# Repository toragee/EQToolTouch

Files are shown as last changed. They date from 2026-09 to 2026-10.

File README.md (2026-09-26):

# EQToolTouch

ESP32-C6 기반 차압(differential pressure) 측정기.
Waveshare **ESP32-C6-Touch-LCD-1.47** 보드에 **XGZP6899A** 아날로그 압력
센서를 붙여, LVGL 차트로 실시간 표시하고 WiFi AP + 웹소켓으로
PC / 안드로이드에 스트리밍한다.

## 저장소 구조

```
EQTool/          아두이노 스케치 (펌웨어)  <- 여기가 본체
  README.md      핀맵, 전원 관리, 문제 해결 기록. 먼저 읽을 것
case/            케이스 설계
  stl/           출력용 STL
  XGZP6899A.step 센서 3D 모델 (데이터시트 도면으로 생성)
  ESP32-C6-Touch-LCD-1.47-2D3D/   보드 2D/3D (Waveshare 배포본)
```

## 브랜치

센서 하드웨어 리비전에 따라 갈라진다.

| 브랜치 | 센서 | 상태 |
|---|---|---|
| `sensor-analog` | **XGZP6899A** 040KPDPN (아날로그, ±40 kPa) | 동작 확인됨. 고정 |
| `main` | 위와 동일 | 현행 개발 라인 |

**현재 두 브랜치의 펌웨어는 같다.** 센서 수급 문제로 교체한 부품
(`6899A040KPDPN`, 각인 `6899 040A`)이 기존과 **동일한 아날로그 부품**이라
코드 변경이 필요 없었다. 판매처가 I2C 라고 표기했더라도 각인을 믿을 것.

`XGZP6899` 바로 뒤 한 글자가 출력 방식이다. **`A` = 아날로그, `D` = I2C.**
`6899A040KPDPN` 은 아날로그, `6899D040KPDPN` 이 I2C 다.
수급 문제로 센서를 바꿀 때 이 글자를 반드시 확인할 것.

### 아날로그 버전(`sensor-analog`)의 특징

- 출력이 ADC 한 핀(**GPIO4**)뿐이라 **약 980 Hz** 로 샘플링한다
- 부팅 시 0.5초 평균으로 영점을 잡고, 그 전압이 VDD 의 몇 %인지로
  DPN(양방향) / DG(단방향)를 자동 판별한다

> **I2C 버전으로 가면 샘플레이트를 유지할 수 없다.** 한 샘플마다
> 변환 명령 → 대기 → 3바이트 읽기가 필요해서 현실적으로 100 Hz 이하가 된다.
> 터치(0x63)·IMU(0x6B)와 버스를 공유하는 부담도 있다.
> 빠른 압력 변화를 봐야 한다면 아날로그 쪽이 유리하다.

## 빠른 시작

1. 아두이노 IDE 2.x, 보드 패키지 **esp32 by Espressif**
2. Waveshare 위키에서 `ESP32-C6-Touch-LCD-1.47-Demo` 를 받아
   그 안의 `Arduino/libraries` 를 스케치북 라이브러리로 설치
   (lvgl 8.4.0 / GFX_Library_for_Arduino 1.5.9 / esp_lcd_touch_axs5106l / FastIMU)
3. `EQTool/EQTool.ino` 를 열고 Tools 설정을 맞춘 뒤 업로드

> **용량이 커서 벤더 데모(155MB)와 zip 파일은 저장소에 포함하지 않았다.**
> 버전이 맞지 않으면 빌드가 조용히 깨지므로, 요구 버전은
> `EQTool/README.md` 의 "빌드" 항목을 그대로 따를 것.

자세한 내용(핀맵, 조작, 전원 관리, 그동안 겪은 문제와 해결)은
**[EQTool/README.md](EQTool/README.md)** 에 정리되어 있다.

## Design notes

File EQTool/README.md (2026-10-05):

# EQTool

ESP32-C6 기반 압력 측정 도구. Waveshare **ESP32-C6-Touch-LCD-1.47** 보드에서
**XGZP6899A** 아날로그 압력 센서를 읽어 LVGL 차트로 실시간 표시하고,
WiFi AP + 내장 웹서버로 PC/안드로이드에 실시간 스트리밍한다.

## 하드웨어

| 항목 | 내용 |
|---|---|
| MCU 보드 | Waveshare **ESP32-C6-Touch-LCD-1.47** (JD9853 172x320 IPS + AXS5106L 터치) |
| 센서 | CFSensor XGZP6899A (40 kPa, 아날로그 전압 출력) |
| 화면 방향 | 가로 (320 x 172), `LCD_ROTATION 3` (Arduino_GFX 기준) |

### 보드 핀맵 (ESP32-C6-Touch-LCD-1.47)

| 기능 | 핀 |
|---|---|
| LCD (JD9853) | SCK=1, MOSI=2, CS=14, DC=15, RST=22, BL=23 |
| TF 카드 | SCK=1, MOSI=2, MISO=3, CS=4 (SPI 공유) |
| 터치 / IMU (I2C) | SDA=18, SCL=19, TP_RST=20, TP_INT=21 |
| 배터리 전압 | GPIO0 (ADC) |
| BOOT 버튼 | GPIO9 (Y축 전환. 화면 터치와 동일 동작) |
| IMU (QMI8658) INT | **GPIO5 = IMU_INT1, GPIO6 = IMU_INT2** |
| **압력 센서 OUT** | **GPIO4** (TF CS 자리) |

> ESP32-C6 의 ADC1 은 GPIO0~6 뿐인데 회로도상 전부 물려 있다.
> GPIO5/GPIO6 은 QMI8658 IMU 가 **능동으로 구동**하므로 아날로그 입력으로 못 쓴다.
> (붙여 보면 센서 출력이 IMU 에 끌려 내려가고 `adc oneshot read fail` 이 뜬다.)
> 남는 선택지는 **GPIO4** 뿐 — TF 카드를 포기하는 대신 쓴다. 10K 풀업이 하나
> 붙어 있지만 센서 출력단 임피던스가 낮아 오차는 무시할 수준이다.
> 데모 코드만 보고 GPIO5/6 이 비었다고 추정하면 안 된다. **회로도를 볼 것.**

### 배선

| 센서 핀 | 신호 | ESP32-C6 | 헤더 |
|---|---|---|---|
| 2 | GND | GND | H1 3 / 4 / 6번 |
| 5 | OUT | **GPIO3** (ADC1_CH3) | **H1 15번 (IO3)** |
| 6 | VDD | 3V3 | H1 8번 |
| 1, 3, 4, 7, 8 | N/C | 연결하지 않음 | |

GPIO4(TF CS)가 아니라 GPIO3(TF MISO)를 쓴다. GPIO4 는 ESP32-C6 의 JTAG
MTMS 겸용이라 리셋 직후 내부 풀업이 걸릴 수 있고, 그러면 "미연결"과
"센서가 레일을 구동 중"을 ADC 값만으로 구분하기 어렵다. GPIO3 은 그런
겸용 기능이 없다. TF 카드는 쓰지 않으므로 둘 다 비어 있다.

#### OUT 핀은 번호로 세지 말고 전압으로 찾을 것

데이터시트의 SOP8 핀 테이블은 **윗면 기준**이다. 센서를 바닥에서 보고
번호를 세면 좌우가 뒤집히고, 그 상태로 배선하면 아무 데이터도 안 들어온다.
센서에 전원(2번 GND / 6번 VDD)만 넣고 리드 8개를 하나씩 찍으면 바로 나온다.

| 측정값 | 정체 |
|---|---|
| 3.3 V | VDD |
| 0 V | GND |
| **1~2 V** | **OUT** |
| 뜨거나 불안정 | N/C |

OUT 자리가 레일(0 V 또는 VDD 근처)에 고착돼 있으면 **센서 불량**이다.
`XGZPA_Init()` 이 무압 출력을 VDD 의 5~90% 범위로 검사해 이 상태를 잡아낸다.

> **주의** — 이 시리즈는 각인으로 출력 타입을 확정할 수 없다.
> CFSensor 품번은 `XGZP6899`**`A`**`040KPDPN` 처럼 출력 타입 글자가 측정 범위
> **앞에** 오는데, 실제 칩 각인은 `6899 040A` 로 **뒤에** 붙어 있어 순서가
> 다르다. 아날로그/I2C 판별은 각인이 아니라 측정으로 할 것:
> 살아 있는(= 서로 다이오드 도통이 보이는) 리드가 3개면 A(아날로그),
> 4개면 D(I2C) 다.

## 소프트웨어 구성

| 파일 | 역할 |
|---|---|
| `EQTool.ino` | 진입점, LVGL 차트 설정, 시리얼 명령 |
| `XGZP6899A.h/.cpp` | 센서 드라이버 (ADC 읽기, 전압→압력 변환, 오토제로) |
| `Pressure_Sampler.h/.cpp` | FreeRTOS 샘플링 태스크 + 락 없는 링버퍼 |
| `Display_LCD.h/.cpp` | LCD 드라이버 — JD9853 초기화 + Arduino_GFX |
| `Touch_AXS5106.h/.cpp` | 정전식 터치 (I2C 0x63) 래퍼 |
| `LVGL_Driver.h/.cpp` | LVGL 연결 (flush / 터치 입력 / 드로우 버퍼) |
| `Battery.h/.cpp` | 배터리 전압 읽기 (BAT_ADC=GPIO0, 200K/100K 분압) |
| `IMU_Orient.h/.cpp` | QMI8658 가속도 읽기 (화면 자동 회전용) |
| `Web_Server.h/.cpp`, `web_page.h` | WiFi AP + WebSocket 스트리밍, 내장 웹 UI |
| `Display_ST7789.h/.cpp` | (구) ST7789 드라이버 — 비워둔 껍데기. 삭제해도 된다 |
| `lv_conf.h` | LVGL 설정 (데모 것 기반, `LV_COLOR_16_SWAP 1`) |
| `ui*.c/.h` | SquareLine Studio 1.6.2 export (LVGL 8.3) |

센서 샘플링(약 800 Hz)은 별도 태스크에서 돌고, UI 는 25 fps 로 링버퍼를 비우며
샘플레이트에 맞춰 자동으로 압축(decimation)한다.

### Y축 프리셋

```c
static const struct { int16_t min, max; uint8_t ticks; const char *name; } Y_PRESETS[] = {
    { -5000, 20000, 6, "-5 ~ 20 kPa" },   /* 눈금 -5/0/5/10/15/20 */
    { -5000, 15000, 5, "-5 ~ 15 kPa" },   /* 눈금 -5/0/5/10/15    */
    { -2000,  8000, 6, "-2 ~ 8 kPa"  },   /* 눈금 -2/0/2/4/6/8    */
};
```

**눈금 간격이 정수 kPa 로 떨어지게 잡아야 한다.** 간격은
`(max - min) / (ticks - 1)` 이다. 예전에 쓰던 `-3 ~ 10 / 6눈금` 은
간격이 2.6 kPa 라 `-3.0 / -0.4 / 2.2 / 4.8 / 7.4 / 10.0` 이 나와서 보기 나빴다.

0 이 눈금선에 오려면 `(0 - min)` 이 간격의 배수여야 한다.
세 프리셋 모두 0 이 아래에서 20~25 % 지점에 오도록 잡았다
(위쪽을 넓게 쓰려는 의도).

Y축 라벨은 그리기 이벤트에서 kPa 로 바꿔 그리며, **소수 자리가 0 이면
정수로만** 표시한다 (`0.0` 대신 `0`).

## 측정 원리

비율식(ratiometric) 아날로그 출력을 ADC 로 읽는다.

```
sens  = 0.80 x VDD / (2 x FS)          # 양방향(DPN) 기준
P(Pa) = (out_mV - zero_mV) / sens x 1000
```

부팅 시 0.5 초간 평균을 내어 영점을 잡고, 그 전압이 VDD 의 몇 % 인지로
DPN(양방향) / DG(단방향) 를 자동 판별한다.

## 빌드

- Arduino IDE 2.x
- 보드: **ESP32C6 Dev Module** (esp32 코어 3.x)
- 라이브러리 (Waveshare 데모 `ESP32-C6-Touch-LCD-1.47-Demo/Arduino/libraries/` 에서 복사)
  - **lvgl 8.3.x**
  - **GFX_Library_for_Arduino** (Arduino_GFX)
  - **esp_lcd_touch_axs5106l**
- `lv_conf.h` 는 스케치 폴더에 같이 들어 있다. lvgl 8.3 은 `__has_include("lv_conf.h")`
  로 스케치 폴더 것을 먼저 찾으므로 `libraries/lv_conf.h` 는 없어도 된다.
  (둘 다 있으면 스케치 폴더 것이 이긴다)
- 스케치북 경로에 **한글/공백이 없어야 한다**. (GCC 상대 include 가 깨진다)
- Tools 설정
  - USB CDC On Boot: **Enabled**
  - CPU Frequency: 160MHz (WiFi)
  - JTAG Adapter: Disabled
  - Flash Size: 4MB, Partition: Default 4MB with spiffs

## 조작

| 동작 | 결과 |
|---|---|
| **화면 짧게 터치** | Y축 스케일 프리셋 순환 (-5~20 → -5~15 → -2~8 kPa) |
| **BOOT 버튼(GPIO9)** | 위와 동일 |
| **꺼진 상태에서 화면 터치** | 다시 켜짐 (깨어난 뒤 재부팅) |
| **30초간 압력 변화 없음** | 자동으로 슬립. 마지막 10초는 `AUTO OFF IN n` 표시 |
| **기기를 뒤집음** | 화면이 180도 자동 회전 (가속도 센서) |

짧은 탭(LVGL `LV_EVENT_SHORT_CLICKED`, 400ms 미만 + 제자리)만 반응한다.
길게 누르기나 드래그는 무시한다. 웹 UI 의 Y축도 보드를 따라간다.

### 부팅 시 배터리 표시

부팅하면 5초간 배터리 잔량을 보여준다(`BAT_SPLASH_MS`). **화면을 터치하면
즉시 건너뛴다.** 블로킹하지 않으므로 그 사이에도 샘플링과 차트는 정상 동작한다.

```
VBAT --[ R21 200K ]--+--[ R22 100K ]-- GND
                     |
                  BAT_ADC (GPIO0)      => VBAT = 읽은 전압 x 3
```

잔량 %는 1셀 LiPo 방전 곡선 표를 선형 보간해서 구한다. 선형
(3.3V=0%, 4.2V=100%)으로 하면 중간 구간이 실제와 크게 어긋난다.

> **USB 가 꽂혀 있으면 충전 IC(ETA6098)가 전압을 끌어올려서 이 값은
> 잔량이 아니라 충전 전압이다.** 그래서 이때는 `CHARGING` 을 같이 표시한다.

> 배터리 ADC 읽기는 **`Pressure_Start()` 앞에서** 한다. 압력 센서도 같은
> ADC1 을 1 kHz 로 쓰기 때문에, 동시에 접근하면
> `adc_oneshot: adc oneshot read fail` 이 날 수 있다.

### 부팅 시 화면

`LCD_Init()` 은 백라이트를 **꺼둔 채로** 준비만 한다(`Backlight_Init()` → duty 0).
`setup()` 에서 `Chart_Init()` 까지 끝난 뒤 `lv_refr_now(NULL)` 로 첫 프레임을
실제로 그리고, 그 다음에 `Set_Backlight(LCD_BL_DEFAULT)` 로 켠다.

이렇게 하지 않으면 LVGL 이 처음 그릴 때까지 1~2초간 검은 화면이 그대로
보인다 (그 사이에 WiFi AP 기동 등이 들어간다).

## 화면 자동 회전 (180도)

QMI8658 가속도 센서(터치와 같은 I2C, 주소 0x6B)를 200ms마다 폴링해서
기기가 뒤집히면 화면을 180도 돌린다.

```c
#define ORIENT_ENABLE       1
#define ORIENT_AXIS         'x'     /* 'x' / 'y' / 'z' */
#define ORIENT_SIGN         (+1)    /* 방향이 반대면 -1 */
#define ORIENT_THRESHOLD    0.35f   /* g */
#define ORIENT_HOLD_MS       700    /* 이만큼 유지돼야 전환 */
#define ORIENT_ROT_NORMAL      3
#define ORIENT_ROT_FLIPPED     1
```

**해상도가 바뀌지 않는 `1 <-> 3` 회전만 쓴다.** 그래서 LVGL 의
`hor_res`/`ver_res` 를 건드릴 필요가 없고, 패널 MADCTL 과 터치 좌표 변환만
바꾸면 된다 (`LCD_SetRotation()` + `Touch_SetRotation()`).

> 회전 후에는 화면 좌표 매핑이 통째로 달라지므로 **전체를 무효화**해야 한다
> (`lv_obj_invalidate(lv_scr_act())` + `lv_layer_top()`). 부분 갱신만
> 하면 이전 내용이 뒤집힌 채로 남는다.

> `Touch_SetRotation()` 은 벤더 드라이버의 파일 스코프 전역 `g_rotation` 을
> 직접 갱신한다. 세터가 없고, `bsp_touch_init()` 을 다시 부르면 리셋 펄스에
> 0.5초가 걸려서 실시간 전환에 못 쓴다.

### 축 맞추기

IMU 가 보드에 어떤 방향으로 붙어 있는지에 따라 `ORIENT_AXIS` / `ORIENT_SIGN`
이 달라진다. 시리얼 **`a`** 로 확인한다.

```
[IMU] ax=+0.98  ay=-0.03  az=+0.11 g   axis 'x' x 1 = +0.98   (threshold 0.35)
```

평소 방향에서 이 값이 **+**, 뒤집었을 때 **−** 가 되는 축을 고른다.
부호가 반대면 `ORIENT_SIGN` 을 `-1` 로.

## 하드웨어 개조

### 센서 노이즈 대책 (R1 / C1~C4)

```
            +-- C1 100nF --+
3V3 --------+-- C2 10uF ---+---- 센서 VDD (6번)
            +--------------+---- GND

센서 OUT (5번) --[ R1 100R ]--+---- GPIO4
                              |
                        C3 10uF   C4 100nF
                              |
                             GND
```

| 부품 | 값 | 역할 |
|---|---|---|
| C1 | 100 nF (X7R) | 센서 VDD 핀 바로 옆. 고주파 디커플링 |
| C2 | 10 uF | 벌크 |
| R1 | **100 R** | C3 와 RC 저역통과 |
| C3 | 10 uF | 주 필터. `fc = 1/(2*pi*100*10u) ~= 159 Hz` |
| C4 | 100 nF | MCU 핀 바로 옆. ADC 샘플홀드 전하 보충 |

**C1 과 C4 는 각각 센서 핀 / MCU 핀에 최대한 붙일 것.**

#### 컷오프 159 Hz 인 이유

XGZP6899 의 응답시간이 2.5 ms(10~90%)라 **센서 자체 대역폭이 약 140 Hz** 다.
그 위는 신호가 아니라 노이즈다. 그리고 약 980 Hz 로 샘플링하므로
나이퀴스트가 490 Hz 인데, 아날로그 필터가 없으면 그 위의 노이즈가
저주파로 접혀 들어온다. **한 번 접힌 것은 소프트웨어 저역통과로 되돌릴 수
없다.** 앨리어싱 방지는 반드시 아날로그 단에서 해야 한다.

#### R1 을 100 R 로 잡은 이유 (중요)

**GPIO4 에는 보드의 10 kR 풀업이 3V3 으로 붙어 있다** (TF 카드 CS 자리).
직렬 저항을 넣으면 이 풀업과 분압이 생겨 **스팬이 압축된다.**

| R1 | 스팬 오차 | 같은 fc 를 내는 C3 |
|---|---|---|
| 1 kR | **-9 %** | 1 uF |
| 100 R | -1 % | 10 uF |

오프셋은 부팅 시 오토제로가 흡수하지만 **기울기 오차는 못 잡는다.**
흔히 쓰는 1 kR 을 넣으면 압력이 9 % 낮게 나온다. 저항을 줄이고 용량을
키울 것.

### R19 제거 — 전원 LED 끄기

```
VSYS ──[ R19 3K ]──▶|── GND
                   LED2
```

**LED2 는 GPIO 가 아니라 VSYS 에 직결된 전원 표시등이다.** 펌웨어로는 끌 수
없고, 슬립 중에도 계속 켜져 있다.

소비 전류는 `(VSYS - Vf) / 3k ≈ 0.6 mA`. **라이트 슬립 상태에서는 이것이
가장 큰 소비원**으로, MCU 슬립 전류보다 훨씬 크다. 그래서 R19 를 떼어낸다.

- LED2 대신 **R19(저항)를 떼는 쪽이 쉽다**
- VSYS 에서 갈라져 나온 막다른 가지라 **떼어도 다른 동작에 영향이 없다**
- 뗀 뒤에는 전원 표시등이 없어진다. 동작 확인은 화면과 시리얼로 한다

> 대기전류를 실제로 재려면 10 mA 분해능의 벤치 파워서플라이로는 안 되고
> µA 를 읽는 장비가 필요하다 (멀티미터 µA 레인지, 전류 프로파일러 등).

## 전원 관리

이 보드에는 전원을 물리적으로 끊는 회로(래칭 로드 스위치)가 없다.
그래서 "전원 끄기" 는 **라이트 슬립**이다.

| | |
|---|---|
| 끄기 | 30초 무변화 시 자동 (또는 시리얼 `o`) |
| 켜기 | 화면 터치 |

### 자동 슬립

`EQTool.ino`

```c
#define AUTO_SLEEP_MS       30000   /* 무변화 지속 시간. 0 = 기능 끔 */
#define AUTO_SLEEP_WARN_MS  10000   /* 마지막 10초는 화면에 카운트다운 */
#define AUTO_SLEEP_PA        200.0f /* 이보다 작은 변화는 "변화 없음" */
```

저역통과를 거친 압력이 `AUTO_SLEEP_PA`(0.2 kPa) 이상 움직이지 않은 채
`AUTO_SLEEP_MS`(30초) 가 지나면 잔다. 다음 중 하나라도 있으면 타이머가 리셋된다.

- 압력이 0.2 kPa 이상 변함
- 화면 터치 (탭 / 누르기 / 떼기)
- 시리얼 입력
- **웹 클라이언트 접속 중** — 누가 폰으로 보고 있으면 자지 않는다
- **USB 케이블이 꽂혀 있음** (`SLEEP_SKIP_ON_USB 1`)

### USB 가 꽂혀 있으면 자지 않는다

**라이트 슬립에 들어가면 USB CDC 가 끊어져 COM 포트가 사라진다.** 시리얼
모니터가 조용해지고 포트 목록에서 없어지는 것이 정상이다. 깨우면(화면 터치)
재부팅되면서 포트가 다시 잡힌다. 개발 중에는 이게 계속 방해가 되고,
USB 로 전원을 받는 중이라면 배터리를 아낄 이유도 없다.

판정은 **`Serial.isPlugged()`** 로 한다. 내부적으로
`usb_serial_jtag_is_connected()` 이고 호스트의 SOF 프레임을 보기 때문에
**시리얼 모니터를 열지 않아도 케이블이 꽂혀 있으면 true** 다.

> `if (Serial)` 은 모니터를 닫으면 false 가 되어 다시 자버린다. 쓰지 말 것.

| 상황 | USB 꽂힘 | 배터리만 |
|---|---|---|
| 30초 무변화 자동 슬립 | 안 함 | 잔다 |
| 시리얼 `o` | **강제로 잔다** (동작 확인용) | 잔다 |

> `AUTO_SLEEP_PA` 를 너무 작게 잡으면 노이즈만으로 계속 리셋되어 영영 자지
> 않는다. 반대로 너무 크면 느린 압력 변화를 측정하는 중에 꺼진다.

끄는 순서: 화면 마지막 프레임 그리기 → 백라이트 off → `gfx->displayOff()`
→ `WiFi.mode(WIFI_OFF)` → 손 뗄 때까지 대기 → `esp_light_sleep_start()`

깨우기: 터치 컨트롤러 INT(**GPIO21**) **LOW 레벨**.
AXS5106L 은 INT 가 평소 HIGH 이고 터치하면 LOW 로 떨어진다
(벤더 드라이버가 FALLING 엣지로 `attachInterrupt` 한다).

> **왜 딥 슬립이 아닌가** — ESP32-C6 의 딥 슬립 GPIO 웨이크업은 **GPIO0~7 만**
> 지원한다. 터치 INT 가 GPIO21 이라 딥 슬립에서는 못 깨운다.
> 대기전류를 더 줄이려면 딥 슬립 + QMI8658 wake-on-motion(GPIO5 = IMU_INT1)
> 으로 바꿀 수 있다. 그 경우 "집어 들면 켜짐" 이 된다.

깨어난 뒤에는 복구하지 않고 **`esp_restart()`** 한다. WiFi AP / 샘플러 /
차트를 부분 복구하는 것보다 재부팅이 안전하고 1초면 올라온다.

**슬립에 들어가기 전 손을 뗄 때까지 기다리는 것이 중요하다.** INT 가 LOW 인
채로 자면 즉시 깨어난다.

## 시리얼 명령 (115200)

| 키 | 동작 |
|---|---|
| `p` | 주기 로그 on/off |
| `z` | 영점 재설정 (양쪽 포트 개방 상태에서) |
| `i` | 현재 상태 1회 출력 |
| `a` | 가속도 1회 출력 (자동 회전 축 맞출 때) |
| `l` | LCD 자가진단 (회전 0/1/2/3 색칠, 6초) |
| `o` | 전원 끄기 (USB 가 꽂혀 있어도 강제) |

## 주요 설정값

`EQTool.ino`

```c
#define CHART_Y_MIN       -5000   // -5 kPa  (아래 20%)
#define CHART_Y_MAX       20000   // +20 kPa (위 80%)
#define CHART_WINDOW_MS    2000   // 가로축 2초
```

`XGZP6899A.h`

```c
#define XGZP_ADC_PIN          3       // H1 15번 (IO3)
#define XGZP_VDD_MV      3300.0f
#define XGZP_FS_KPA        40.0f      // 마킹 040 = 40 kPa
#define XGZP_SPAN_RATIO     0.80f     // ※ 추정치. 실측 보정 전
#define XGZP_OVERSAMPLE      16
```

> LVGL 8 의 `lv_coord_t` 는 int16 이라 차트 값은 Pa 단위로 ±32767 이 한계다.
> Y축 라벨은 그리기 이벤트에서 kPa 로 변환해 표시한다.

## 문제 해결 기록

### 업로드가 `A serial exception error occurred: Write timeout` 으로 실패

증상: 컴파일은 되는데 `Connecting...` 에서 바로 실패. 보드를 새것으로 바꿔도,
BOOT+RESET / BOOT 누른 채 USB 삽입으로 다운로드 모드에 넣어도 동일.
포트 자체는 정상 인식됨 (`COM8 (ESP32 Family Device)`, VID `0x303A` / PID `0x1001`).

원인: **Windows 쪽 COM 포트 드라이버**. 포트를 열기는 되는데 write 가 막힌 상태였다.

해결: 장치 관리자 → 포트(COM & LPT) → 해당 COM → **디바이스 제거**
(`이 장치의 드라이버를 삭제합니다` 체크) → USB 재연결 →
Windows 가 기본 `USB Serial Device` 를 새로 설치하게 함.

> 보드나 케이블을 의심하기 전에 드라이버를 먼저 보자.
> 보드 2개에서 똑같이 실패하면 거의 항상 PC 쪽이다.

### 시리얼 로그가 전혀 안 나옴

Tools → **USB CDC On Boot** 가 `Disabled` 면 `Serial` 이 USB 가 아니라
UART0(GPIO16/17) 로 간다. 이 보드는 반드시 **`Enabled`**.

### `Sketch too big` (1310720 bytes 초과)

Tools → Partition Scheme → **`Huge APP (3MB No OTA/1MB SPIFFS)`**.
용량의 대부분은 WiFi + HTTP 서버 스택이라 LVGL 을 깎아도 효과가 없다.

### USB C-to-C 케이블로는 CDC 인식 안 됨

이 보드는 **C-to-A 케이블**을 쓸 것. C-to-C 는 다운로드 모드는 잡혀도
CDC 포트가 안 뜬다.

### 부팅 직후 `Guru Meditation Error: ... (Store access fault)` — Chart_Init 에서

원인: **LVGL 8.4.0 버그**. `lv_chart_add_series()` 가 LINE/BAR 차트에서
`ser->x_points` / `ser->x_ext_buf_assigned` 를 초기화하지 않는데
(SCATTER 일 때만 채운다), 8.4.0 의 `lv_chart_remove_series()` 는

```c
if (!series->x_ext_buf_assigned && series->x_points) lv_mem_free(series->x_points);
```

를 실행한다. 시리즈 노드는 `lv_mem_alloc` 으로 잡히므로 두 필드에 쓰레기가
남아 있고, 그 쓰레기 포인터를 free 하다가 죽는다.

LVGL **8.3.10** 의 `remove_series` 에는 이 줄이 없다. 그래서 이전 보드
(ESP32-C6-LCD-1.47, lvgl 8.3.10) 에서는 같은 코드가 멀쩡히 돌았고,
터치 보드용 데모의 **lvgl 8.4.0** 으로 바꾸면서 드러났다.

우회: `EQTool.ino` 의 `chart_fix_series_x()` — 시리즈를 만들거나 넘겨받은
직후 `x_points = NULL`, `x_ext_buf_assigned = 0` 으로 직접 비운다.

> `lv_chart_remove_series()` 를 부르는 코드가 있다면 반드시 같이 적용할 것.

### LVGL 라벨에 %f 를 쓰면 "f" 가 찍힌다

`lv_label_set_text_fmt()` / `lv_snprintf()` 는 LVGL 자체 최소 구현이라
**부동소수점 포맷을 지원하지 않는다** (`lv_conf.h` 의 `LV_SPRINTF_USE_FLOAT`
기본값 0). `"%.2f V"` 를 쓰면 값 대신 `f` 가 그대로 나온다.

정수 두 개로 쪼개서 소수점을 직접 만든다.

```c
uint32_t mvi = (uint32_t)(mv + 0.5f);
lv_label_set_text_fmt(txt, "%u.%02u V", mvi / 1000, (mvi % 1000) / 10);
```

`Serial.printf()` 는 진짜 printf 라 `%f` 가 정상 동작한다. 헷갈리기 쉽다.

### 화면이 안 나올 때 — 펌웨어인지 하드웨어인지 가르기

부팅 로그가 아래처럼 **전부** 나온다면 펌웨어는 정상이다.

```
[LCD] backlight GPIO23  pwm=on  (off until first frame)
[LCD] JD9853 ready  320x172  rot=3
read: 8161                          <- 터치 칩 I2C 응답
[Touch] AXS5106L init  ...
[LVGL] init  320x172  ...
[EQTool] Y range -> -5 ~ 20 kPa     <- Chart_Init 완료
[WEB] AP "EQTool"  ...
[EQTool] setup done  ...
```

판정 요령

- **`[WEB] AP` 가 찍혔다 = 백라이트를 켜는 코드가 실행됐다.**
  `setup()` 순서가 `Chart_Init()` → `lv_refr_now()` → `Set_Backlight()` →
  `Web_Start()` 이기 때문이다. 켜라고 했는데 안 켜지면 하드웨어다.
- **`read: 8161` 이 있다 = FPC 가 꽂혀 있고 TP_VDD 도 들어간다.**
  LCD 와 터치는 같은 17핀 FPC(J3)를 쓴다. 터치만 되고 화면이 죽었다면
  LCD 쪽 핀(2~7)이나 백라이트 핀(8 LEDK / 9 LEDA)의 접촉 불량을 의심한다.
- 시리얼 **`l`** 로 언제든 `LCD_SelfTest()` 를 돌릴 수 있다. 백라이트를 강제로
  켜고 회전 0/1/2/3 을 색으로 칠한다(6초). 같은 펌웨어로 정상 보드와
  비교하는 것이 가장 빠르다.
- 어두운 곳에서 화면 가장자리에 미세한 빛이 새는지 본다.
  샌다 = 백라이트는 살아 있고 패널 데이터 쪽 문제. 완전히 깜깜 = LEDK/LEDA 쪽.

> 실제 사례: 두 보드에 같은 바이너리를 올렸는데 한쪽만 화면이 안 나왔다.
> 로그는 두 보드가 한 글자도 다르지 않았고, 결론은 그 보드의 하드웨어 문제.

### 새 센서에서 데이터가 전혀 안 들어올 때 (HW 리비전 기록)

기존 센서가 단종되어 같은 `6899 / 040A` 각인 제품으로 교체했는데, 받은 물건
**2개가 연속으로 DOA** 였다. 증상과 진단 과정을 남겨둔다 — 같은 함정을 두 번
밟지 않기 위해서.

**증상**

- GPIO4 가 3082~3333 mV 레일에 붙어 있고 압력에 전혀 반응하지 않음
- 센서를 교체해도 동일
- 혹시 I2C 품인가 싶어 SDA/SCL 을 물리면 **버스 전체가 죽음**
  (보드 내장 터치 0x63, IMU 0x6B 까지 스캔에서 사라짐).
  SDA 가 0.5 V 로 클램프되고 약 280 µA 를 싱크하고 있었다.

**최종 원인**

센서 2개가 모두 불량. 출력단이 레일에 고착된 상태였다. 배선도 핀 배열도
처음부터 맞았다.

**결론을 낸 측정**

전원을 넣은 상태에서 센서 리드 8개의 전압을 하나씩 찍는 것. 단 한 번으로 끝났다.

| 개체 | OUT 자리 전압 | 판정 |
|---|---|---|
| 1번 | 3.0 V | 레일 고착 — 불량 |
| 2번 | 0 V | 바닥 고착 — 불량 |
| 3번 | **1.1 V** | 정상 |

**배운 것**

- "같은 배치에서 2개 연속 불량은 드물다"를 "그러니 다른 원인이 있다"로
  바꾸지 말 것. 드문 일은 일어난다. 이 전제 하나 때문에 핀 매핑 오류,
  180° 회전, 하우징 변형 같은 가설을 차례로 쌓았고 전부 빗나갔다.
- 전압을 측정하면 바로 나오는 것을, 전압에서 **추론**하려 들면 길어진다.
  "3082 mV = 풀업만 있는 플로팅", "0.5 V = 전원 핀" 같은 해석은 전부
  그럴듯했지만 틀렸다.
- 부품 상태를 묻는 질문에는 **부품을 직접 재는 측정**이 답한다.
  보드를 통해 간접적으로 보면 보드의 문제와 구분되지 않는다.

**관련 도구**

- `SensorTest/` — I2C 1초 자동 스캔 + GPIO3/GPIO4 동시 ADC 읽기.
  I2C 응답 목록이 **바뀔 때만** 출력하므로, 배선을 흔들면서 접촉 불량을
  추적할 수 있다.
- `PinTest/` — 핀이 떠 있는지(내부 풀업만) 아니면 뭔가가 구동 중인지를
  아날로그 / 풀다운 / 풀업 3단계로 판별.

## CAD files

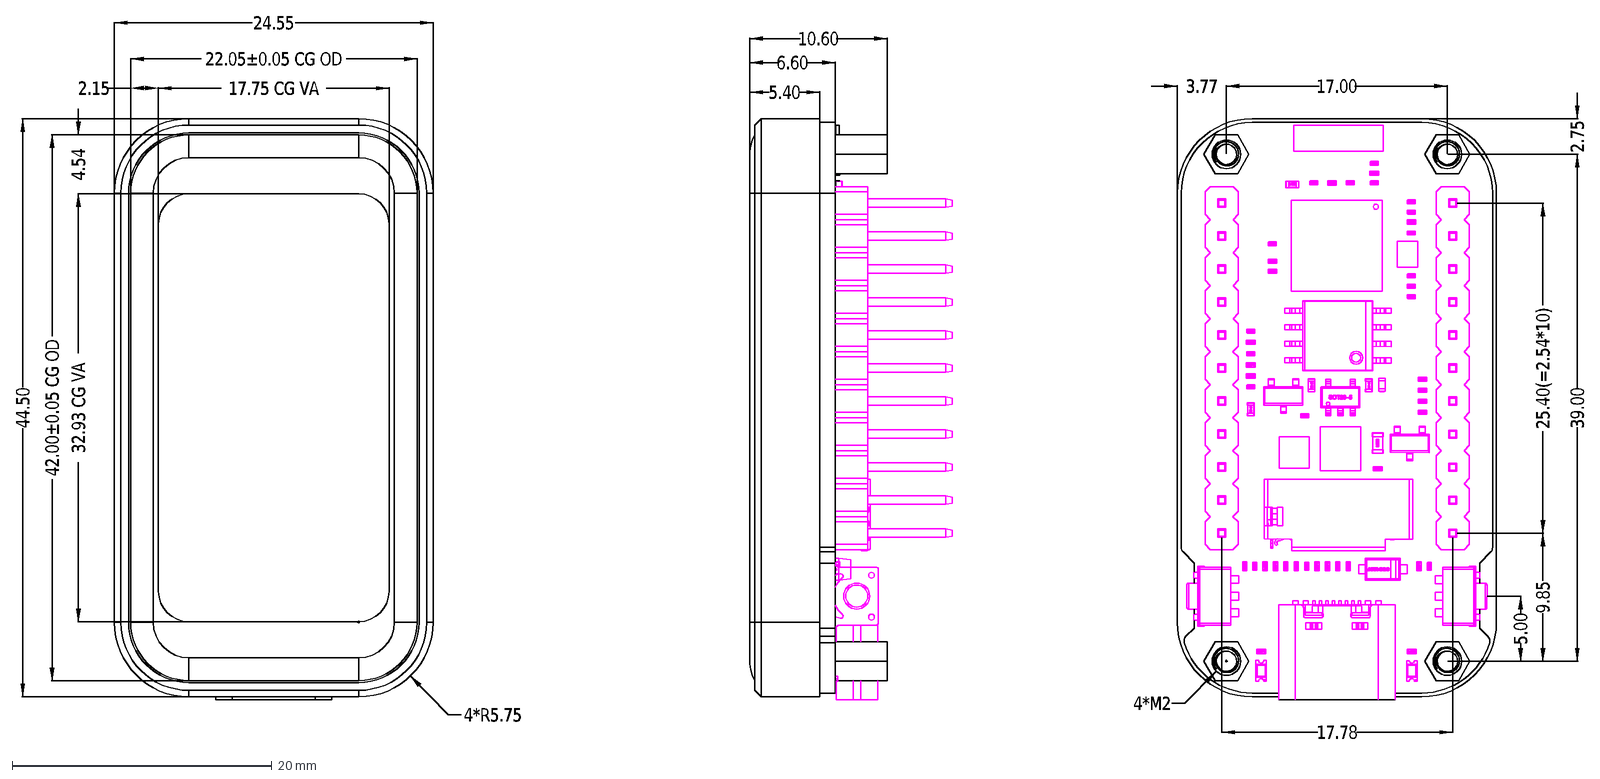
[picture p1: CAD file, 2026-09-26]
case/ESP32-C6-Touch-LCD-1.47-2D3D/ESP32-C6-Touch-LCD-1.47_20250411.dxf
17.75 CG VA
32.93 CG VA
22.05±0.05 CG OD
42.00±0.05 CG OD
4.54
2.15
24.55
44.50
5.40
6.60
10.60
4*R5.75
17.00
3.77
39.00
5.00
9.85
25.40(=2.54*10)
17.78
2.75
4*M2

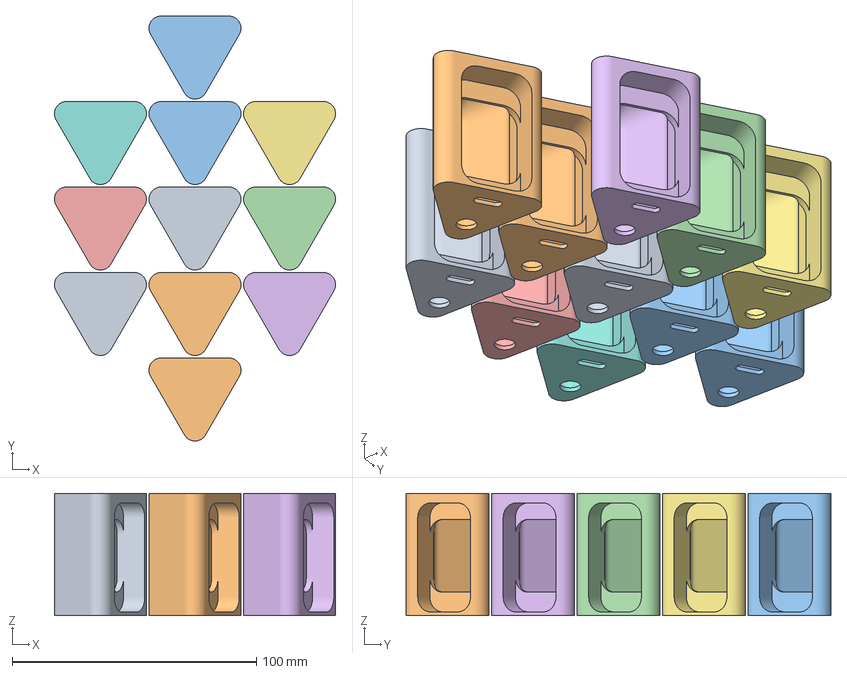
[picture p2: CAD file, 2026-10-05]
case/stl/eqtool_final_1.3mf
115.1 x 174.0 x 50.0 mm
eqtool_final_1 x 11

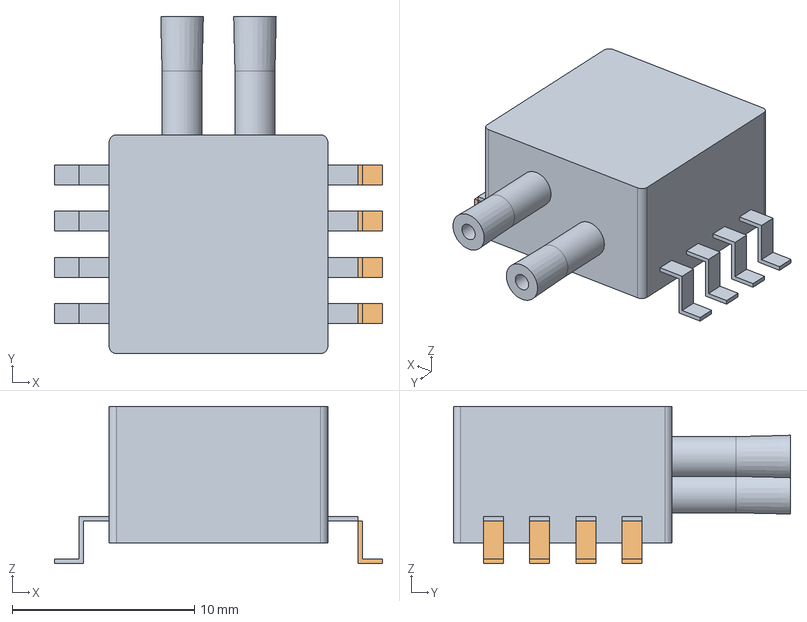
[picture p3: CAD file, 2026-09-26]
case/XGZP6899A.step
18.0 x 18.5 x 8.63 mm

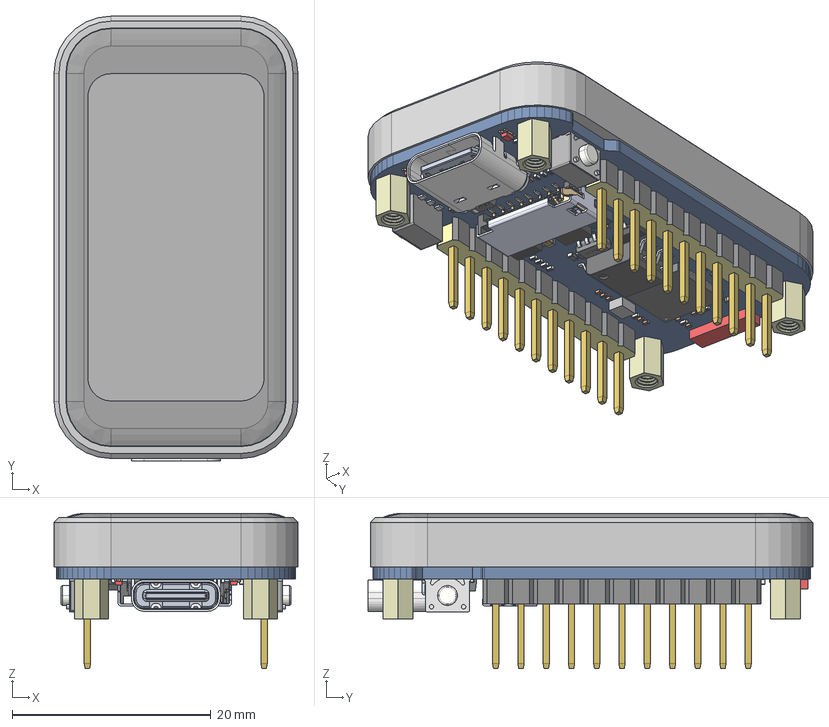
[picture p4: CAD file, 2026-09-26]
case/ESP32-C6-Touch-LCD-1.47-2D3D/ESP32-C6-Touch-LCD-1_47_20250411.stp
24.6 x 44.7 x 15.6 mm
HSX01470105002B-A0
HSX0147024Y15-A0
BOARD
USER_LIBRARY-0201_0603M__CAP_1 x 18
USER_LIBRARY-0201_0603M__CAP_2 x 18
USER_LIBRARY-0201_0603M__CAP_3 x 18
3_1_A x 4
3_1_2_A
SOD123F
L0402_1
L0402_2
L0402_3
EXTRUDED-113096
USER_LIBRARY-RES_0603-0201_1 x 25
USER_LIBRARY-RES_0603-0201_2 x 25
USER_LIBRARY-RES_0603-0201_3 x 25
USER_LIBRARY-RES_0603-0201_4 x 25
EXTRUDED-308014
ALSROBOT-SOT23 x 2
USER_LIBRARY-QFN56_0_4
PIN_SOIC_SOIC-208_1 x 8
SOIC_150_SOIC_5_4X5_4_1
EXTRUDED-353291
SOT23-5AND6_00 x 5
SOT23-5-14065_AF0
EXTRUDED-410514
SWITCHER-4_5X3_3XH3_4 x 2
__X2_00BB00C900C600AC_X0__STE_1
__X2_00BB00C900C600AC_X0__STE_2
__X2_00BB00C900C600AC_X0__STE_3
__X2_00BB00C900C600AC_X0__STE_4
__X2_00BB00C900C600AC_X0__STE_5
__X2_00BB00C900C600AC_X0__STE_6
__X2_00BB00C900C600AC_X0__STE_7
__X2_00BB00C900C600AC_X0__STE_8
__X2_00BB00C900C600AC_X0__STE_9
__X2_00BB00C900C600AC_X0__ST_10
_X2_00BD00BA00CC00E5_X0__STEPEP
__X2_00CC00FA00BF00C7_X0__STEPE
USER_LIBRARY-LED_0603_R_-488467 x 2
USER_LIBRARY-LED_0603_R_PAD004 x 2
USER_LIBRARY-LED_0603_R_FILLET x 2
USER_LIBRARY-LED_0603_R_-490822 x 2
USER_LIBRARY-LED_0603_R_PAD x 2
HEX_STUDS-M2XH4XL3 x 4
PIN_HEADER-2_54MM_1X11PIN x 2
TP-LCD-CONNECTOR
ESP32-TOUCH-LCD-1_47-BOX

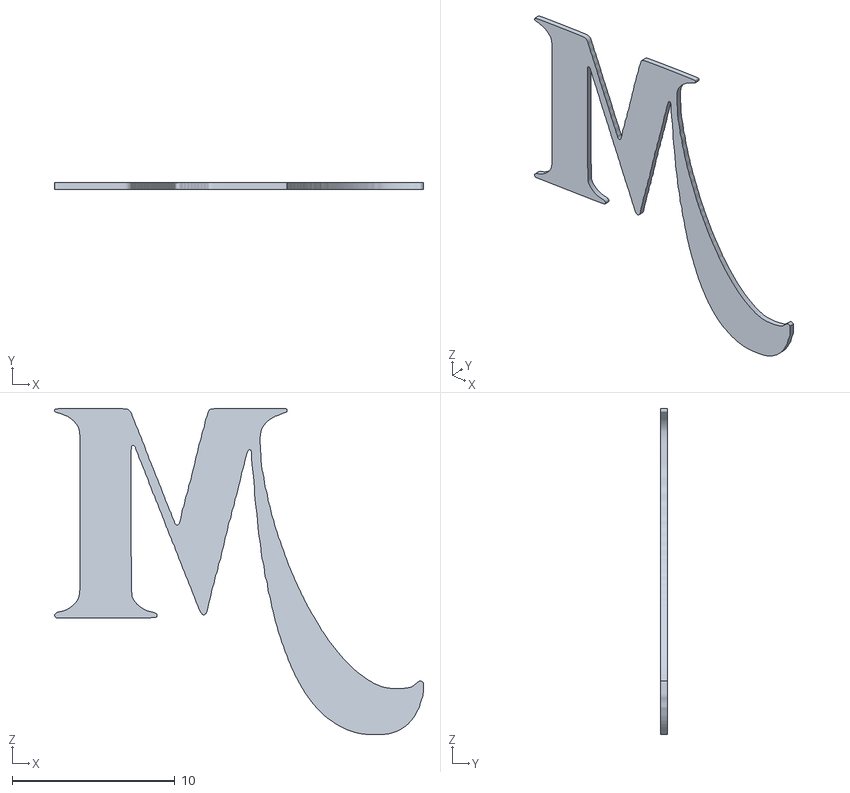
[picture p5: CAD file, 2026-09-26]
case/stl/eqtool_final_2.stl
22.6 x 0.4 x 20.0

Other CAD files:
case/stl/eqtool_final_1.stl

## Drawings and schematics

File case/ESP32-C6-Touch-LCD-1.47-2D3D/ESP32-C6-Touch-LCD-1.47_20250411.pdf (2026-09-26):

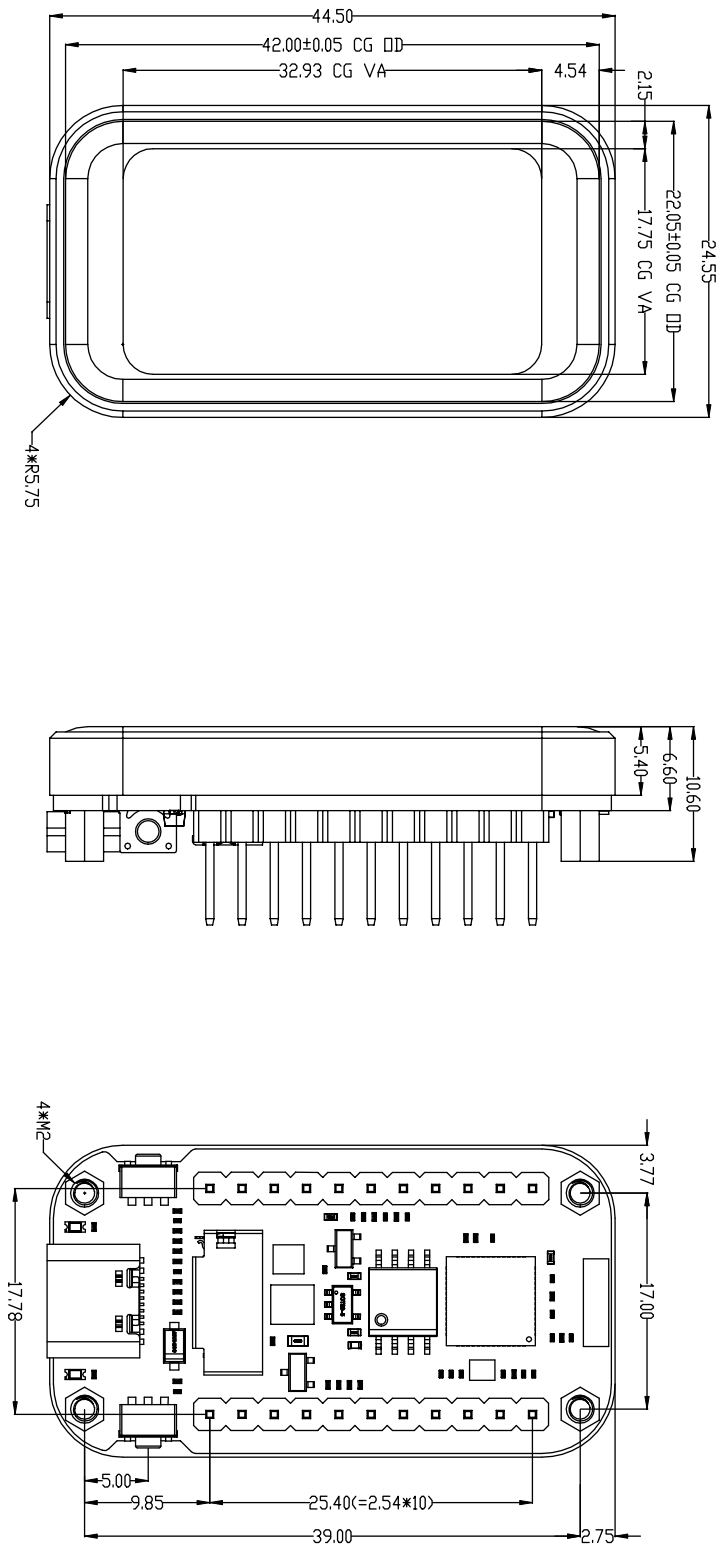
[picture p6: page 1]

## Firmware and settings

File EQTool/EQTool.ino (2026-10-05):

#include <math.h>

#include "Display_LCD.h"
#include "LVGL_Driver.h"
#include "XGZP6899A.h"
#include "Pressure_Sampler.h"
#include "Web_Server.h"
#include "Touch_AXS5106.h"
#include "Battery.h"
#include "IMU_Orient.h"

#include <WiFi.h>
#include <esp_sleep.h>
#include <driver/gpio.h>
#include <soc/soc_caps.h>
#if SOC_USB_SERIAL_JTAG_SUPPORTED
  #include <HWCDC.h>        /* HWCDC::isPlugged() - USB 케이블 연결 판정 */
#endif
#include "ui.h"

/* ===================== 차트 표시 설정 =========================================
 *  차트 내부 값은 항상 Pa 로 넣는다 (분해능 확보).
 *  Y축 라벨만 그리기 이벤트에서 kPa 로 바꿔 그린다.
 *
 *  LVGL 8 의 lv_coord_t 는 int16_t 라 Pa 단위로는 +-32767 Pa 가 한계다.
 *  (= +-32.7 kPa. 풀스케일 +-40 kPa 전체를 보려면 Pa 대신 hPa 로 넣어야 한다)
 *
 *  0 Pa 위치: 아래에서 20% 지점 -> 위쪽 80%, 아래쪽 20%
 *  major tick 6개라 눈금이 -5, 0, 5, 10, 15, 20 kPa 로 딱 떨어진다.
 * ========================================================================== */
/* Y축 프리셋. 보드의 BOOT 버튼을 누를 때마다 순환한다.
 *   ticks 는 major tick 수. 0 kPa 가 눈금선에 오려면
 *   (0 - min) 이 (max-min)/(ticks-1) 의 배수여야 한다. */
#define BOOT_BTN_PIN          9         /* ESP32-C6 온보드 BOOT 버튼 */

static const struct {
    int16_t     min, max;
    uint8_t     ticks;
    const char *name;
} Y_PRESETS[] = {
    { -5000, 20000, 6, "-5 ~ 20 kPa" },   /* 눈금 -5/0/5/10/15/20 */
    { -5000, 15000, 5, "-5 ~ 15 kPa" },   /* 눈금 -5/0/5/10/15    */
    { -2000,  8000, 6, "-2 ~ 8 kPa"  },   /* 눈금 -2/0/2/4/6/8 (간격 2 kPa)  */
};
#define Y_PRESET_CNT  (sizeof(Y_PRESETS) / sizeof(Y_PRESETS[0]))

static uint8_t y_preset = 0;
#define CHART_POINTS        100
#define CHART_WINDOW_MS    2000         /* 차트 가로축이 담는 시간 폭 */
#define DRAW_MS              40         /* 화면 갱신 25 fps */

/* ===================== 로그 설정 ==========================================
 *   LOG_PERIODIC : 1초마다 압력값을 계속 출력한다. 평소에는 0 을 권장.
 *                  실행 중 시리얼 모니터에서 'p' 를 보내면 토글된다.
 *   그 외(부팅 정보, 센서 초기화 결과, 경고)는 항상 출력된다.
 *
 *   시리얼 명령:  p = 주기 로그 토글 / z = 영점 재설정 / i = 현재 상태 1회
 * ========================================================================= */
#define LOG_PERIODIC          0

/* ===== 전원 끄기 =========================================================
 *  진입은 30초 무변화 자동 슬립(또는 시리얼 'o')뿐이다. 화면 롱프레스는 쓰지 않는다.
 *
 *  이 보드에는 전원을 물리적으로 끊는 회로가 없다. 그래서 "전원 끄기" 는
 *  라이트 슬립이고, 깨우기는 터치 컨트롤러의 INT(GPIO21) 레벨 웨이크업이다.
 *
 *  왜 딥 슬립이 아닌가: ESP32-C6 의 딥 슬립 GPIO 웨이크업은 GPIO0~7 만
 *  지원한다. 터치 INT 는 GPIO21 이라 딥 슬립에서는 못 깨운다.
 *
 *  AXS5106L 은 INT 가 평소 HIGH 이고 터치 시 LOW 로 떨어진다
 *  (벤더 드라이버가 FALLING 엣지로 attachInterrupt 한다).
 *  따라서 GPIO_INTR_LOW_LEVEL 로 깨운다.
 *
 *  깨어난 뒤에는 복구하지 않고 esp_restart() 한다. WiFi AP / 샘플러 /
 *  차트를 부분 복구하는 것보다 재부팅이 훨씬 안전하고, 1초면 올라온다.
 * ====================================================================== */
/* --- 자동 슬립 -----------------------------------------------------------
 *  압력이 AUTO_SLEEP_PA 이상 움직이지 않은 채 AUTO_SLEEP_MS 가 지나면 잔다.
 *  터치, 시리얼 명령, 웹 클라이언트 접속 중에는 타이머가 계속 리셋된다.
 *  AUTO_SLEEP_MS 를 0 으로 두면 기능이 꺼진다.
 *  AUTO_SLEEP_PA 는 센서 노이즈보다 넉넉히 크게 잡아야 한다. 저역통과를
 *  거친 값을 쓰므로 200 Pa(0.2 kPa)면 충분하다. 너무 작으면 영영 안 잔다.
 * ---------------------------------------------------------------------- */
#define AUTO_SLEEP_MS       30000   /* 무변화 지속 시간. 0 = 기능 끔 */
#define AUTO_SLEEP_WARN_MS  10000   /* 남은 시간이 이보다 적으면 경고 표시 */
#define AUTO_SLEEP_PA        200.0f /* 이보다 작은 변화는 "변화 없음" 으로 본다 */

/*  USB 가 꽂혀 있으면 슬립하지 않는다.
 *  라이트 슬립에 들어가면 USB CDC 가 끊어져 COM 포트가 사라진다.
 *  개발 중에는 이게 계속 방해가 되고, USB 로 전원을 받는 중이라면
 *  배터리를 아낄 이유도 없다.
 *
 *  판정은 Serial.isPlugged() 로 한다. 내부적으로 usb_serial_jtag_is_connected()
 *  이고 호스트의 SOF 프레임을 보기 때문에, 시리얼 모니터를 열지 않아도
 *  케이블이 꽂혀 있으면 true 다. (if (Serial) 은 모니터를 닫으면 false 가 된다.)
 *
 *  적용 범위: 자동 슬립.
 *  시리얼 'o' 명령만은 강제로 재운다 (개발 중 슬립 동작 확인용).
 *  0 으로 두면 USB 와 무관하게 전부 동작한다. */
#define SLEEP_SKIP_ON_USB   1

/* --- 화면 자동 회전 (180도) ---------------------------------------------
 *  가속도 센서로 기기가 뒤집혔는지 보고 화면을 180도 돌린다.
 *  해상도가 바뀌지 않는 1 <-> 3 회전만 쓰므로 LVGL 설정은 건드릴 필요가 없다.
 *  (0 <-> 2 는 세로용. 가로 화면인 우리는 1/3 만 쓴다.)
 *
 *  ORIENT_AXIS / ORIENT_SIGN 은 보드에 IMU 가 어떤 방향으로 붙어 있느냐에
 *  달렸다. 시리얼 'a' 로 현재 가속도를 찍어보고 맞추면 된다.
 *  기기를 평소 방향으로 세웠을 때 해당 축이 +, 뒤집으면 - 가 되어야 한다.
 * --------------------------------------------------------------------- */
#define ORIENT_ENABLE       1
#define ORIENT_AXIS         'x'     /* 'x' / 'y' / 'z' */
#define ORIENT_SIGN         (-1)    /* 축은 맞고 방향만 반대여서 뒤집었다 (+1 <-> -1) */
#define ORIENT_THRESHOLD    0.35f   /* g. 이보다 기울어야 전환을 고려 */
#define ORIENT_HOLD_MS       700    /* 이만큼 유지돼야 실제로 전환 (떨림 방지) */
#define ORIENT_POLL_MS       200    /* IMU 읽는 주기 */
#define ORIENT_ROT_NORMAL      3    /* 평소 방향 */
#define ORIENT_ROT_FLIPPED     1    /* 180도 뒤집힘 */

static lv_obj_t     *po_label     = NULL;   /* 자동 슬립 카운트다운 표시 */
static volatile bool power_off_req = false; /* 실제 종료는 loop() 에서 */

static uint32_t idle_t0  = 0;       /* 마지막 "활동" 시각 */
static float    idle_ref = 0.0f;    /* 그때의 압력 (Pa) */

static lv_chart_series_t *press_ser   = NULL;
static lv_chart_series_t *zero_ser    = NULL;   /* 0 기준선 */
static bool               log_periodic = (LOG_PERIODIC != 0);

/* USB 케이블이 꽂혀 있는가 (호스트 SOF 기준. 모니터 개폐와 무관) */
static inline bool usb_plugged(void)
{
#if SLEEP_SKIP_ON_USB && SOC_USB_SERIAL_JTAG_SUPPORTED
    /* 클래스의 static 멤버를 직접 부른다.
       Serial.isPlugged() 로 쓰면 Tools -> USB CDC On Boot 가 Disabled 일 때
       Serial 이 HardwareSerial(UART0) 이라 컴파일이 깨진다.
       HWCDC::isPlugged() 는 usb_serial_jtag_is_connected() 래퍼라
       CDC 설정과 무관하게 USB 호스트 연결 여부를 알려준다. */
    return HWCDC::isPlugged();
#else
    return false;
#endif
}

/* 뭔가 "활동" 이 있었다. 자동 슬립 타이머를 처음부터 다시 센다. */
static void activity_reset(void)
{
    idle_t0  = millis();
    idle_ref = Pressure_GetFilteredPa();
}

/* 길게 누르는 동안 남은 시간을 표시한다. 손을 떼면 취소. */
static void po_label_show(const char *what, int sec_left)
{
    if (!po_label) return;
    lv_label_set_text_fmt(po_label, "%s %d", what, sec_left);
    lv_obj_clear_flag(po_label, LV_OBJ_FLAG_HIDDEN);
}

static void po_label_hide(void)
{
    if (po_label) lv_obj_add_flag(po_label, LV_OBJ_FLAG_HIDDEN);
}

#if ORIENT_ENABLE
static uint8_t       cur_rot = ORIENT_ROT_NORMAL;
static volatile int8_t rot_req = -1;     /* 실제 적용은 loop() 에서 */

/* 선택한 축의 가속도(g)를 돌려준다 */
static float orient_axis_g(float ax, float ay, float az)
{
    float g;
    switch (ORIENT_AXIS) {
        case 'y': g = ay; break;
        case 'z': g = az; break;
        default:  g = ax; break;
    }
    return g * ORIENT_SIGN;
}

/* ORIENT_POLL_MS 마다 IMU 를 보고, 임계값을 ORIENT_HOLD_MS 동안 계속
   넘으면 회전 요청을 건다. 손에서 잠깐 흔들리는 정도로는 안 바뀐다. */
static void orient_poll(void)
{
    static uint32_t t_poll = 0, t_cand = 0;
    static uint8_t  cand   = 0xFF;

    uint32_t now = millis();
    if (now - t_poll < ORIENT_POLL_MS) return;
    t_poll = now;

    float ax, ay, az;
    if (!IMU_ReadAccel(&ax, &ay, &az)) return;

    float   g    = orient_axis_g(ax, ay, az);
    uint8_t want = cur_rot;

    if      (g >  ORIENT_THRESHOLD) want = ORIENT_ROT_NORMAL;
    else if (g < -ORIENT_THRESHOLD) want = ORIENT_ROT_FLIPPED;
    /* 임계값 사이(눕혀놓은 상태 등)에서는 현재 방향을 유지한다 */

    if (want == cur_rot) { cand = 0xFF; return; }

    if (cand != want) { cand = want; t_cand = now; return; }

    if (now - t_cand >= ORIENT_HOLD_MS) {
        cand    = 0xFF;
        rot_req = (int8_t)want;
    }
}

/* 패널 회전 + 터치 좌표 변환을 같이 바꾸고 화면을 통째로 다시 그린다.
   LVGL 이벤트/타이머 안에서 부르면 안 된다. loop() 에서만 호출할 것. */
static void Screen_SetRotation(uint8_t r)
{
    cur_rot = r;

    LCD_SetRotation(r);
    Touch_SetRotation(r);

    /* 회전이 바뀌면 화면 좌표 매핑이 통째로 달라진다.
       부분 갱신으로는 이전 내용이 남으므로 전체를 무효화한다. */
    lv_obj_invalidate(lv_scr_act());
    lv_obj_invalidate(lv_layer_top());
    lv_refr_now(NULL);

    Serial.printf("[EQTool] screen rotation -> %u (%s)\n",
                  r, (r == ORIENT_ROT_NORMAL) ? "normal" : "flipped");
}
#endif /* ORIENT_ENABLE */

static void draw_timer_cb(lv_timer_t *timer)
{
    LV_UNUSED(timer);

    poll_boot_button();

#if ORIENT_ENABLE
    orient_poll();
#endif

    static double   acc   = 0.0;
    static uint32_t n     = 0;
    static uint32_t decim = 1;
    static uint32_t t_log = 0;

    uint32_t rate = Pressure_GetRateHz();
    if (rate > 0) {
        uint32_t d = (rate * CHART_WINDOW_MS / 1000) / CHART_POINTS;
        decim = (d < 1) ? 1 : d;
    }

    float pa;
    while (Pressure_Pop(&pa)) {
        acc += pa;
        if (++n >= decim) {
            long v = lroundf((float)(acc / n));          /* Pa 그대로 */
            if (v < Y_PRESETS[y_preset].min) v = Y_PRESETS[y_preset].min;
            if (v > Y_PRESETS[y_preset].max) v = Y_PRESETS[y_preset].max;
            if (press_ser) lv_chart_set_next_value(ui_Chart1, press_ser, (lv_coord_t)v);
            acc = 0.0;
            n   = 0;
        }
    }

    /* ===== 자동 슬립 ====================================================
       압력이 오래 안 움직이면 잔다.

       ※ 센서가 없거나 고장이어도 잔다. 예전에는 이 블록 전체를
         Pressure_IsOk() 로 감싸는 바람에, 센서를 안 꽂은 보드가 영영
         깨어 있으면서 배터리만 먹었다. 센서가 없으면 압력 변화가 있을
         리 없으니, 오히려 자야 하는 상황이다. */
#if AUTO_SLEEP_MS > 0
    if (!power_off_req) {
        /* 웹으로 누가 보고 있으면 자지 않는다 */
        if (Web_GetClientCount() > 0) activity_reset();

        /* USB 가 꽂혀 있으면 자지 않는다 */
        if (usb_plugged()) activity_reset();

        /* 압력 변화는 센서가 정상일 때만 "활동" 으로 친다 */
        static bool was_ok = false;
        bool        now_ok = Pressure_IsOk();

        if (now_ok) {
            if (!was_ok) {
                /* 막 정상이 됐다. 기준값이 낡았으므로 다시 잡는다
                   (부팅 직후 오토제로가 끝나는 시점이 여기다) */
                activity_reset();
            } else {
                float cur = Pressure_GetFilteredPa();
                if (fabsf(cur - idle_ref) > AUTO_SLEEP_PA) activity_reset();
            }
        }
        was_ok = now_ok;

        uint32_t idle = millis() - idle_t0;

        if (idle >= AUTO_SLEEP_MS) {
            Serial.printf("[EQTool] idle %us (%s) -> auto sleep\n",
                          (unsigned)(AUTO_SLEEP_MS / 1000),
                          Pressure_IsOk() ? "no pressure change" : "sensor not connected");
            power_off_req = true;
        } else if (idle >= AUTO_SLEEP_MS - AUTO_SLEEP_WARN_MS) {
            po_label_show("AUTO OFF IN",
                          (int)((AUTO_SLEEP_MS - idle + 999) / 1000));
        } else {
            po_label_hide();
        }
    }
#endif

    uint32_t now = millis();
    if (now - t_log >= 1000) {
        t_log = now;

        /* --- 경고: 센서 미준비 (5초에 한 번만) --- */
        if (!Pressure_IsOk()) {
            static uint32_t t_warn = 0;
            if (now - t_warn >= 5000) {
                t_warn = now;
                Serial.printf("[EQTool] waiting for sensor - OUT=GPIO%d reads %.1f mV\n",
                              XGZP_ADC_PIN, XGZPA_ReadMv());
            }
            return;
        }

        /* --- 경고: 링버퍼 오버런 (발생했을 때만) --- */
        static uint32_t last_drop = 0;
        uint32_t drop = Pressure_GetDropped();
        if (drop != last_drop) {
            Serial.printf("[EQTool] WARNING: %u samples dropped (UI too slow)\n",
                          (unsigned)(drop - last_drop));
            last_drop = drop;
        }

        /* --- 주기 로그 (기본 off) --- */
        if (log_periodic)
            Serial.printf("P=%8.1f Pa   out=%7.1f mV   rate=%u Hz\n",
                          Pressure_GetFilteredPa(), Pressure_GetLastMv(),
                          (unsigned)Pressure_GetRateHz());
    }
}

/* 시리얼 한 글자 명령 */
static void Serial_Command(void)
{
    while (Serial.available()) {
        activity_reset();
        switch (Serial.read()) {
        case 'p':
        case 'P':
            log_periodic = !log_periodic;
            Serial.printf("[EQTool] periodic log %s\n", log_periodic ? "ON" : "OFF");
            break;
        case 'z':
        case 'Z':
            Serial.println("[EQTool] re-zeroing - keep both ports open");
            Pressure_Rezero();
            break;
        case 'a':
        case 'A': {
            float ax = 0, ay = 0, az = 0;
            if (!IMU_ReadAccel(&ax, &ay, &az)) {
                Serial.println("[IMU] not available");
                break;
            }
#if ORIENT_ENABLE
            Serial.printf("[IMU] ax=%+.2f  ay=%+.2f  az=%+.2f g   "
                          "axis '%c' x %d = %+.2f   (threshold %.2f)\n",
                          ax, ay, az, ORIENT_AXIS, ORIENT_SIGN,
                          orient_axis_g(ax, ay, az), ORIENT_THRESHOLD);
#else
            Serial.printf("[IMU] ax=%+.2f  ay=%+.2f  az=%+.2f g\n", ax, ay, az);
#endif
            break;
        }
        case 'l':
        case 'L':
            Serial.println("[EQTool] LCD selftest (6s) - watch the panel");
            LCD_SelfTest();
            lv_obj_invalidate(lv_scr_act());   /* 자가진단이 덮어쓴 화면 복구 */
            lv_refr_now(NULL);
            Set_Backlight(LCD_BL_DEFAULT);
            break;
        case 'o':
        case 'O':
            Serial.println("[EQTool] power off requested (serial, forced)");
            power_off_req = true;      /* USB 가 꽂혀 있어도 강제로 잔다 */
            break;
        case 'i':
        case 'I':
            Serial.printf("[EQTool] P=%.1f Pa  out=%.1f mV  zero=%.1f mV  rate=%u Hz  drop=%u  heap=%u\n",
                          Pressure_GetFilteredPa(), Pressure_GetLastMv(),
                          XGZPA_GetZeroMv(), (unsigned)Pressure_GetRateHz(),
                          (unsigned)Pressure_GetDropped(), (unsigned)ESP.getFreeHeap());
            break;
        default:
            break;
        }
    }
}

/* Y축 눈금 라벨을 kPa 로 다시 쓴다.
   차트 값은 Pa 이므로 1000 으로 나눠 소수 첫째 자리까지 표기한다. */
static void chart_draw_event_cb(lv_event_t *e)
{
    lv_obj_draw_part_dsc_t *dsc = lv_event_get_draw_part_dsc(e);

    if (!lv_obj_draw_part_check_type(dsc, &lv_chart_class, LV_CHART_DRAW_PART_TICK_LABEL))
        return;
    if (dsc->id != LV_CHART_AXIS_PRIMARY_Y || dsc->text == NULL)
        return;

    int32_t pa    = dsc->value;
    bool    minus = (pa < 0);
    int32_t a     = minus ? -pa : pa;

    int whole = (int)(a / 1000);
    int frac  = (int)((a % 1000) / 100);

    /* 소수 자리가 0 이면 아예 빼서 "0.0" 대신 "0" 으로 보이게 한다.
       프리셋 눈금이 전부 정수 kPa 라 평소에는 소수점이 나오지 않는다. */
    if (frac == 0)
        lv_snprintf(dsc->text, dsc->text_length, "%s%d", minus ? "-" : "", whole);
    else
        lv_snprintf(dsc->text, dsc->text_length, "%s%d.%d", minus ? "-" : "", whole, frac);
}

/* 웹(Web_Server.cpp)이 현재 Y축 범위를 프레임에 실어 보내기 위해 호출한다 */
void EQ_GetYRange(int16_t *lo, int16_t *hi)
{
    if (lo) *lo = Y_PRESETS[y_preset].min;
    if (hi) *hi = Y_PRESETS[y_preset].max;
}

/* Y축 범위/눈금을 프리셋에 맞춰 갱신한다 */
static void apply_y_preset(uint8_t i)
{
    y_preset = i % Y_PRESET_CNT;
    const uint8_t t = Y_PRESETS[y_preset].ticks;

    lv_chart_set_range(ui_Chart1, LV_CHART_AXIS_PRIMARY_Y,
                       Y_PRESETS[y_preset].min, Y_PRESETS[y_preset].max);
    lv_chart_set_axis_tick(ui_Chart1, LV_CHART_AXIS_PRIMARY_Y, 10, 5, t, 2, true, 40);
    lv_chart_set_div_line_count(ui_Chart1, t, 5);
    lv_chart_refresh(ui_Chart1);

    Serial.printf("[EQTool] Y range -> %s\n", Y_PRESETS[y_preset].name);
}

/* BOOT 버튼(GPIO9) 폴링. 40ms 안정화 후 눌린 순간에만 반응한다.
   GPIO9 는 스트래핑 핀이라 리셋 시점에만 부팅 모드에 영향을 준다.
   실행 중에 누르는 것은 무해하다.
   터치와 같은 동작을 하며, 둘 다 쓸 수 있다. */
static void poll_boot_button(void)
{
    static bool     stable   = true;    /* 풀업이라 안 눌린 상태가 HIGH */
    static bool     raw_prev = true;
    static uint32_t t_last   = 0;

    bool     raw = digitalRead(BOOT_BTN_PIN);
    uint32_t ms  = millis();

    if (raw != raw_prev) { raw_prev = raw; t_last = ms; return; }
    if (ms - t_last < 40) return;                  /* 디바운스 */

    if (raw != stable) {
        stable = raw;
        if (!stable) apply_y_preset(y_preset + 1); /* HIGH -> LOW = 눌림 */
    }
}

/* 화면을 짧게 터치하면 Y축 프리셋이 순환한다.
   (이전에는 BOOT 버튼(GPIO9)으로 했다. 터치 패널이 생겨서 그쪽으로 옮겼다.)

   LV_EVENT_SHORT_CLICKED 는 누른 시간이 LVGL 의 long-press 기준(기본 400ms)보다
   짧고, 손가락을 뗀 위치가 누른 위치와 같을 때만 발생한다. 즉 "짧은 탭" 이다.
   길게 누르기나 드래그(차트 스크롤)에는 반응하지 않는다.

   차트가 화면 대부분을 덮고 있고 LVGL 은 기본적으로 이벤트를 부모로 올리지
   않으므로, 화면과 차트 양쪽에 같은 콜백을 건다. */
#define TOUCH_MIN_INTERVAL_MS  300      /* 이보다 빠른 연속 탭은 무시 (떨림 방지) */

/* 화면을 건드리면 자동 슬립 타이머를 다시 센다.
   (짧은 탭은 touch_tap_cb 가 따로 받는다. 여기서는 누르는 순간만 본다.) */
static void touch_press_cb(lv_event_t *e)
{
    if (lv_event_get_code(e) == LV_EVENT_PRESSED) activity_reset();
}

/* 라이트 슬립으로 들어간다. 터치하면 깨어나고, 깨면 그냥 재부팅한다. */
static void Power_Off(void)
{
    Serial.println("[EQTool] power off -> light sleep  (touch screen to wake)");
    Serial.flush();

    /* 1. 화면에 마지막 상태를 한 번 그려준 뒤 끈다 */
    lv_timer_handler();
    delay(150);
    Backlight_Sleep();          /* LEDC 떼고 핀을 LOW 로 고정 */
    gfx->displayOff();

    /* 2. WiFi 를 내린다. AP 가 살아 있으면 라이트 슬립이 유지되지 않는다. */
    WiFi.mode(WIFI_OFF);
    delay(50);

    /* 3. 손을 뗄 때까지 기다린다.
          INT 가 LOW 인 채로 슬립에 들어가면 즉시 깨버린다. */
    pinMode(TOUCH_PIN_INT, INPUT_PULLUP);
    uint32_t t0 = millis();
    while (digitalRead(TOUCH_PIN_INT) == LOW && (millis() - t0 < 5000)) {
        Touch_GetPoint(NULL, NULL);        /* 읽어서 INT 를 해제시킨다 */
        delay(20);
    }
    delay(100);

    /* 4. 터치 INT LOW 레벨로 깨우도록 등록하고 잔다 */
    gpio_wakeup_enable((gpio_num_t)TOUCH_PIN_INT, GPIO_INTR_LOW_LEVEL);
    esp_sleep_enable_gpio_wakeup();

    Serial.flush();
    esp_light_sleep_start();               /* ← 여기서 멈춘다 */

    /* 5. 깨어남. 부분 복구 대신 깔끔하게 재부팅한다. */
    gpio_wakeup_disable((gpio_num_t)TOUCH_PIN_INT);
    Serial.println("[EQTool] wake by touch -> restart");
    Serial.flush();
    delay(50);
    esp_restart();
}

static void touch_tap_cb(lv_event_t *e)
{
    LV_UNUSED(e);

    static uint32_t t_last = 0;
    uint32_t        now    = millis();

    if (now - t_last < TOUCH_MIN_INTERVAL_MS) return;
    t_last = now;

    activity_reset();
    apply_y_preset(y_preset + 1);
}

/* ===== LVGL 8.4.0 버그 우회 =========================================
 *  lv_chart_add_series() 는 LINE/BAR 차트에서 ser->x_points 와
 *  ser->x_ext_buf_assigned 를 초기화하지 않는다 (SCATTER 일 때만 채운다).
 *  시리즈 노드는 lv_mem_alloc 으로 잡히므로 두 필드에는 쓰레기가 들어간다.
 *
 *  그런데 8.4.0 의 lv_chart_remove_series() 는
 *      if (!ser->x_ext_buf_assigned && ser->x_points) lv_mem_free(ser->x_points);
 *  를 실행한다. → 쓰레기 포인터를 free 하다가 Store access fault 로 죽는다.
 *
 *  LVGL 8.3.10 의 remove_series 에는 이 줄이 없어서 이전 보드
 *  (ESP32-C6-LCD-1.47) 에서는 드러나지 않았다.
 *
 *  시리즈를 만들거나 넘겨받은 직후에 x 쪽을 직접 비워 두면 안전하다.
 * ================================================================== */
static void chart_fix_series_x(lv_chart_series_t *ser)
{
    if (!ser) return;
    ser->x_points           = NULL;
    ser->x_ext_buf_assigned = 0;
}

/* ===== 부팅 시 배터리 표시 =============================================
 *  최상위 레이어에 전체 화면 패널을 띄우고 BAT_SPLASH_MS 뒤에 지운다.
 *  화면을 터치하면 즉시 건너뛴다.
 *  블로킹하지 않으므로 그 사이에도 샘플링과 차트는 정상 동작한다.
 * ===================================================================== */
#define BAT_SPLASH_MS   5000

static lv_obj_t *bat_splash = NULL;

static void bat_splash_close(bool async)
{
    if (!bat_splash) return;
    lv_obj_t *o = bat_splash;
    bat_splash = NULL;                 /* 재진입 방지 */
    if (async) lv_obj_del_async(o);    /* 이벤트 콜백 안에서는 async 로 */
    else       lv_obj_del(o);
}

static void bat_splash_timer_cb(lv_timer_t *t)
{
    lv_timer_del(t);
    bat_splash_close(false);
}

static void bat_splash_click_cb(lv_event_t *e)
{
    LV_UNUSED(e);
    activity_reset();                  /* 자동 슬립 타이머도 리셋 */
    bat_splash_close(true);            /* 콜백 안 -> async 삭제 */
}
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
void loop()
{
    Serial_Command();
    Timer_Loop();

#if ORIENT_ENABLE
    if (rot_req >= 0) {
        uint8_t r = (uint8_t)rot_req;
        rot_req = -1;
        Screen_SetRotation(r);
    }
#endif

    /* LVGL 이벤트 안에서 바로 자면 위험하므로 여기서 처리한다 */
    if (power_off_req) {
        power_off_req = false;
        Power_Off();
    }

    delay(1);
}

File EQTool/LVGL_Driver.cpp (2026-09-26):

/*****************************************************************************
 *  LVGL_Driver.cpp  -  ESP32-C6-Touch-LCD-1.47
 *
 *  바뀐 점 (이전 ESP32-C6-LCD-1.47 대비)
 *   - flush 를 Arduino_GFX 의 draw16bitBeRGBBitmap 으로 (JD9853)
 *   - 드로우 버퍼를 static 배열 -> heap_caps_malloc (내부 RAM)
 *   - full_refresh 제거 (부분 버퍼라 사용 불가)
 *   - Lvgl_Touchpad_Read 를 AXS5106L 실제 구현으로 교체 (이전엔 더미)
 ****************************************************************************/
#include "LVGL_Driver.h"
#include "Touch_AXS5106.h"

static lv_disp_draw_buf_t  draw_buf;
static lv_color_t         *disp_draw_buf = NULL;

/* Serial debugging */
void Lvgl_print(const char *buf)
{
    Serial.printf("[LVGL] %s", buf);
    Serial.flush();
}

void Lvgl_Display_LCD(lv_disp_drv_t *disp_drv, const lv_area_t *area, lv_color_t *color_p)
{
    LCD_addWindow(area->x1, area->y1, area->x2, area->y2, (uint16_t *)&color_p->full);
    lv_disp_flush_ready(disp_drv);
}

/* 터치패드 읽기 */
void Lvgl_Touchpad_Read(lv_indev_drv_t *indev_drv, lv_indev_data_t *data)
{
    LV_UNUSED(indev_drv);

    uint16_t x, y;
    if (Touch_GetPoint(&x, &y)) {
        data->point.x = (lv_coord_t)x;
        data->point.y = (lv_coord_t)y;
        data->state   = LV_INDEV_STATE_PRESSED;
    } else {
        data->state   = LV_INDEV_STATE_RELEASED;
    }
}

/* lv_conf.h 의 LV_TICK_CUSTOM 이 1 이면 LVGL 이 millis() 를 직접 읽으므로
   lv_tick_inc() 자체가 컴파일되지 않는다. 그래서 같이 조건부로 둔다. */
#if LV_TICK_CUSTOM == 0
void example_increase_lvgl_tick(void *arg)
{
    LV_UNUSED(arg);
    lv_tick_inc(EXAMPLE_LVGL_TICK_PERIOD_MS);
}
#endif

void Lvgl_Init(void)
{
    lv_init();

#if LV_USE_LOG != 0
    lv_log_register_print_cb(Lvgl_print);
#endif

    disp_draw_buf = (lv_color_t *)heap_caps_malloc(LVGL_BUF_LEN * sizeof(lv_color_t),
                                                   MALLOC_CAP_INTERNAL | MALLOC_CAP_8BIT);
    if (!disp_draw_buf) {
        Serial.println("[LVGL] draw buffer alloc failed - halted");
        while (1) delay(1000);
    }
    lv_disp_draw_buf_init(&draw_buf, disp_draw_buf, NULL, LVGL_BUF_LEN);

    /* Display */
    static lv_disp_drv_t disp_drv;
    lv_disp_drv_init(&disp_drv);
    disp_drv.hor_res  = LVGL_WIDTH;
    disp_drv.ver_res  = LVGL_HEIGHT;
    disp_drv.flush_cb = Lvgl_Display_LCD;
    disp_drv.draw_buf = &draw_buf;
    lv_disp_drv_register(&disp_drv);

    /* Touch */
    Touch_Init();

    static lv_indev_drv_t indev_drv;
    lv_indev_drv_init(&indev_drv);
    indev_drv.type    = LV_INDEV_TYPE_POINTER;
    indev_drv.read_cb = Lvgl_Touchpad_Read;
    lv_indev_drv_register(&indev_drv);

    /* lv_conf.h 가 LV_TICK_CUSTOM 1 이면 millis() 를 쓰므로 타이머가 필요 없다. */
#if LV_TICK_CUSTOM == 0
    const esp_timer_create_args_t lvgl_tick_timer_args = {
        .callback = &example_increase_lvgl_tick,
        .name     = "lvgl_tick"
    };
    esp_timer_handle_t lvgl_tick_timer = NULL;
    esp_timer_create(&lvgl_tick_timer_args, &lvgl_tick_timer);
    esp_timer_start_periodic(lvgl_tick_timer, EXAMPLE_LVGL_TICK_PERIOD_MS * 1000);
#endif

    Serial.printf("[LVGL] init  %ux%u  buf=%u px (%u byte)  heap=%u\n",
                  (unsigned)LVGL_WIDTH, (unsigned)LVGL_HEIGHT,
                  (unsigned)LVGL_BUF_LEN, (unsigned)(LVGL_BUF_LEN * sizeof(lv_color_t)),
                  (unsigned)ESP.getFreeHeap());
}

void Timer_Loop(void)
{
    lv_timer_handler();
}

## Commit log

2026-09-26 ESP32-C6-Touch-LCD-1.47 포팅 + 웹 스트리밍 / 전원 관리 / 화면 자동회전
    보드를 ESP32-C6-LCD-1.47 에서 터치 버전으로 옮기고, 그 과정에서 필요한
    기능들을 추가했다.
    디스플레이 / 터치
    - Display_LCD.* : JD9853 패널을 Arduino_GFX 로 구동 (기존 ST7789 직접
    제어 코드 대체). 부팅 시 첫 프레임을 그린 뒤 백라이트를 켜서 검은 화면이
    보이지 않게 함. 시리얼 'l' 로 회전 0/1/2/3 자가진단 가능
    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
2026-09-26 저장소 루트를 D:\EQTool 로 올리고 케이스 설계 파일 추가
    펌웨어만 담고 있던 저장소에 케이스 설계까지 함께 두기 위해
    저장소 루트를 한 단계 위로 옮겼다.
    - 기존 스케치 파일들을 EQTool/ 하위로 이동 (git 이 rename 으로 인식하므로
    히스토리는 그대로 유지된다)
    - case/ 추가 : 출력용 STL, XGZP6899A STEP 모델,
    Waveshare 보드 2D/3D 배포본
    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
    [ESP32-C6-Touch-LCD-1.47_20250411.dxf, ESP32-C6-Touch-LCD-1_47_20250411.stp, XGZP6899A.step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]
2026-09-26 README 에 브랜치 구성 정리
    센서 하드웨어 리비전에 따라 브랜치를 나눈다.
    - sensor-analog : XGZP6899A (아날로그, ±40 kPa). 동작 확인된 버전
    - main : 현행 개발 라인
    부품번호에서 XGZP6899 바로 뒤 한 글자가 출력 방식(A=아날로그, D=I2C)이라
    센서 교체 시 반드시 확인해야 한다는 점, 그리고 I2C 로 가면 샘플레이트가
    980Hz 에서 100Hz 이하로 떨어진다는 점을 함께 적었다.
    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
2026-09-26 README: 교체 센서가 동일 아날로그 부품임을 기록
    수급 문제로 받은 6899A040KPDPN 의 칩 각인이 6899 040A 로,
    기존 센서와 동일한 아날로그 ±40 kPa 부품이었다.
    판매처 표기와 달리 I2C 가 아니므로 드라이버 변경 없이 그대로 사용한다.
    부품번호와 각인 모두 XGZP6899 뒤 한 글자(A/D)가 출력 방식을 가리킨다.
    교체 시에는 판매처 설명보다 각인을 확인할 것.
    Claude-Session: https://claude.ai/code/session_01Vbd4KzPTrRWUf6B7MYEKHK
2026-10-05 센서 OUT 을 GPIO3 으로 옮기고 진단 스케치 추가
    교체 센서에서 데이터가 전혀 안 들어오던 문제를 정리한다.
    원인은 받은 센서 2개가 연속 DOA 였던 것 (출력단이 각각 3.0V / 0V
    레일에 고착). 배선도 핀 배열도 처음부터 맞았다.
    - XGZP_ADC_PIN 4 -> 3 (H1 15번). GPIO4 는 ESP32-C6 의 JTAG MTMS
    겸용이라 리셋 직후 내부 풀업이 걸릴 수 있어, 미연결과 센서 구동을
    ADC 값만으로 구분하기 어렵다. GPIO3 은 그런 겸용 기능이 없다.
    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
    [eqtool_final_1.3mf]
